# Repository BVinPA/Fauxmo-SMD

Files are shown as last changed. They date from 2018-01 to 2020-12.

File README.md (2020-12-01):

# Fauxmo-SMD
Surface mount version of the Fauxmo controller board.  Includes Eagle files for the schematic and board, along with STLs for an enclosure.  There are two options for the bottom - a solid one, or one with a hole if you are using a right-angle programming header. The full project is here: https://www.electroschematics.com/home-iot-voice-controlled-lab-lights-amazon-alexa-esp8266/

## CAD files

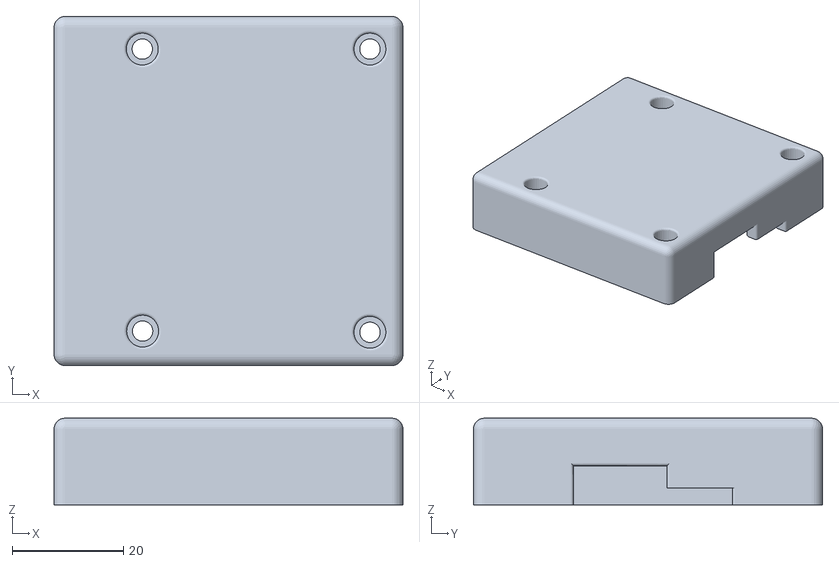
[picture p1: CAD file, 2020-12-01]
fauxmo-top.stl
62.8 x 62.9 x 15.6

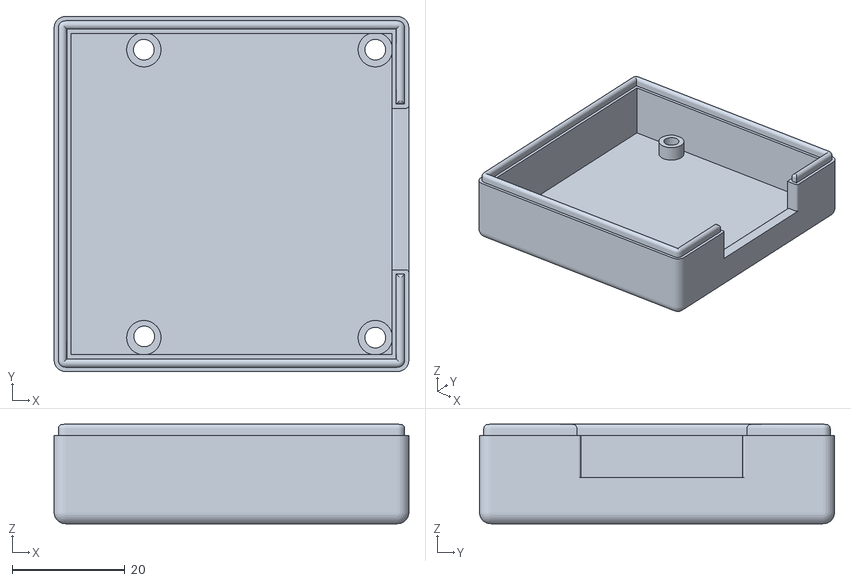
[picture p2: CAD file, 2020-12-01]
fauxmo-bottom.stl
62.8 x 62.9 x 17.6

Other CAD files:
fauxmo-bottom-hole.stl

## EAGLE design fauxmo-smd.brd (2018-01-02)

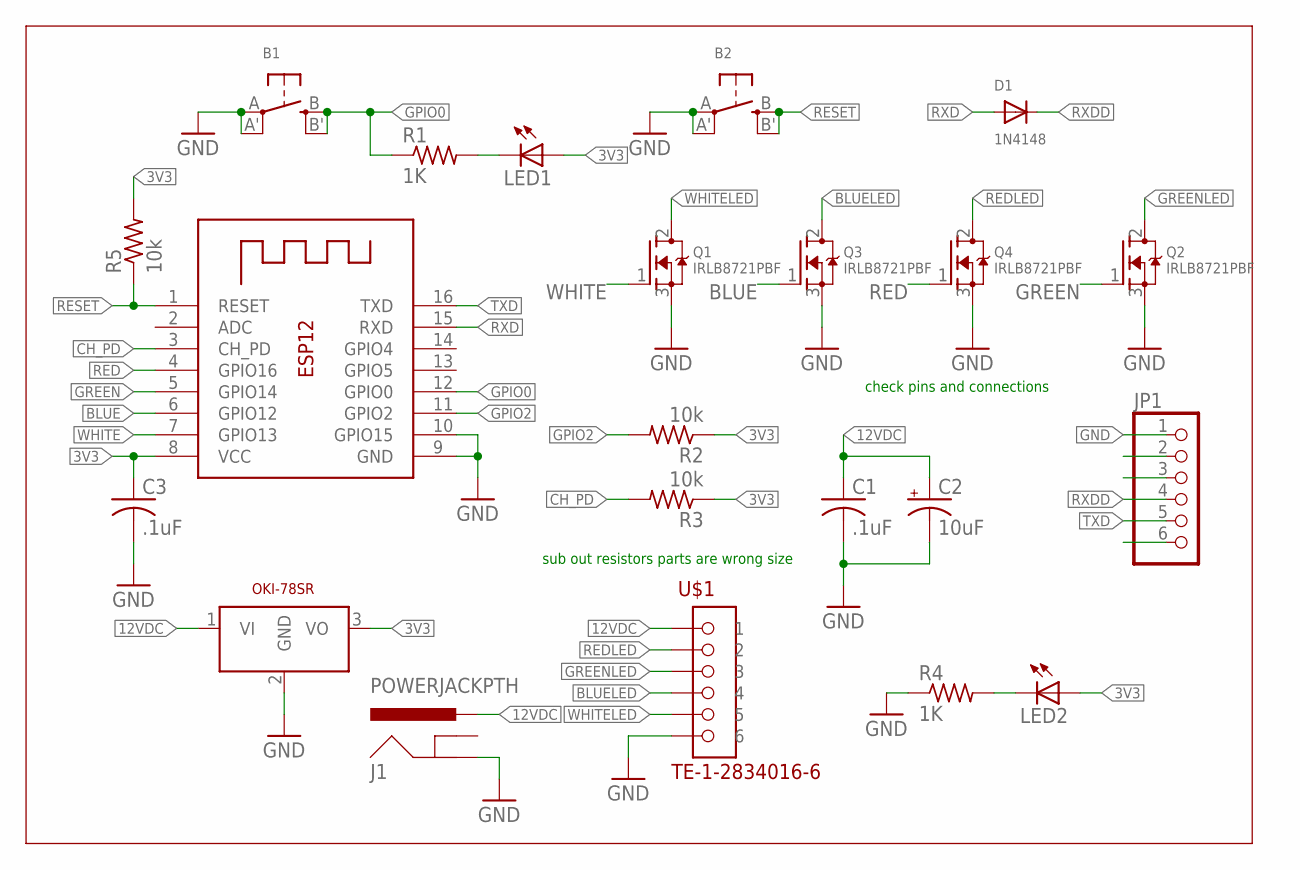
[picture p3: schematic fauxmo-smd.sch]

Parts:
B1, B2: SWITCH_TACT_SMT; EVQ-Q2
C1, C3: .1uF; C0805
C2: 10uF; E2,5-5
D1: 1N4148; SOD-123
J1: POWERJACKPTH; BARREL-2.1
JP1: PINHD-1X6; 1X06
LED1, LED2: LEDCHIP-LED0805; CHIP-LED0805
OKI: DCDC_OKI-78SROKI-78SRV; OKI-78SRH
Q1, Q2, Q3, Q4: IRLB8721PBF; TO220V
R1, R4: 1K; R0805
R2, R3, R5: 10k; R0805
U$1: TE-1-2834016-6
X1: ESP-12

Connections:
3V3: C3.1, LED1.A, LED2.A, OKI.3 (VO), R2.1, R3.1, R5.2, X1.8 (VCC)
12VDC: C1.1, C2.+, J1.PWR, OKI.1 (VI), U$1.P$6 (1)
BLUE: Q3.1 (G), X1.6 (GPIO12)
BLUELED: Q3.2 (D), U$1.P$3 (4)
CH_PD: R3.2, X1.3 (CH_PD)
GND: B1.A, B1.A' (P1), B2.A, B2.A' (P1), C1.2, C2.-, C3.2, J1.GND, JP1.1, OKI.2 (GND), Q1.3 (S), Q2.3 (S), Q3.3 (S), Q4.3 (S), R4.1, U$1.P$1 (6), X1.9 (GND), X1.10 (GPIO15)
GPIO0: B1.B (S), B1.B' (S1), R1.1, X1.12 (GPIO0)
GPIO2: R2.2, X1.11 (GPIO2)
GREEN: Q2.1 (G), X1.5 (GPIO14)
GREENLED: Q2.2 (D), U$1.P$4 (3)
unnamed: LED1.C, R1.2
unnamed: LED2.C, R4.2
RED: Q4.1 (G), X1.4 (GPIO16)
REDLED: Q4.2 (D), U$1.P$5 (2)
RESET: B2.B (S), B2.B' (S1), R5.1, X1.1 (RESET)
RXD: D1.A, X1.15 (RXD)
RXDD: D1.C, JP1.4
TXD: JP1.5, X1.16 (TXD)
WHITE: Q1.1 (G), X1.7 (GPIO13)
WHITELED: Q1.2 (D), U$1.P$2 (5)

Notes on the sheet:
OKI-78SR
sub out resistors parts are wrong size
check pins and connections

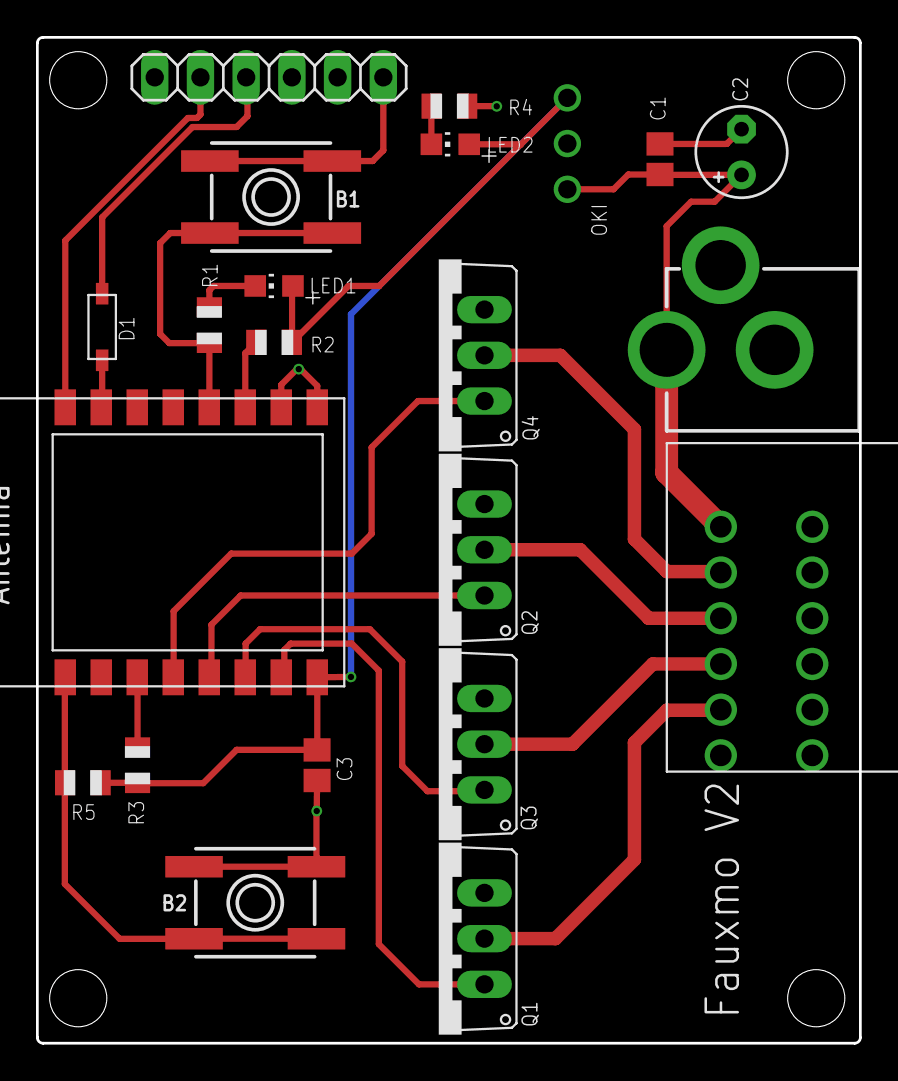
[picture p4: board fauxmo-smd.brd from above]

Board: 2 copper layers, 45.7 x 55.9 mm, 23 parts (1 on the bottom side), 20 nets.

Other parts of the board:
U$2: OSHW_5MM

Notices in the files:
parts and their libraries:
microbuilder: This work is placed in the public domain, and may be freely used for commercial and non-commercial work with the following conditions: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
